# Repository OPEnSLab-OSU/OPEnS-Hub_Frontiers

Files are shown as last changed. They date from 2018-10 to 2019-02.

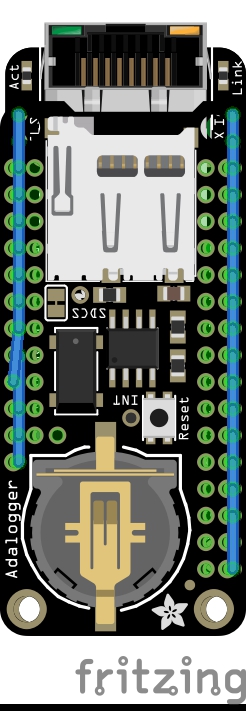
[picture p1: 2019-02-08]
Wiring/HubWiringDiagram_bb.jpg

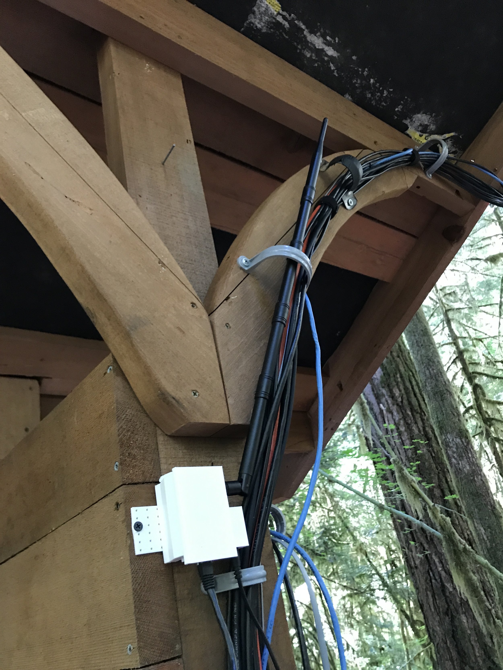
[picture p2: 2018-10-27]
Hub Images/Receiver.jpg

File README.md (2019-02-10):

# OPEnS-Hub_Frontiers


This is the Data, CAD, and Code archive for the OPEnS Hub Project for access by Frontiers

[Project Page](http://www.open-sensing.org/lora-hub)

[Project Loom Repository](https://github.com/OPEnSLab-OSU/InternetOfAg) that this is a instance/subset of 

## Development Boards

This project used the Adafruit line of Development boards called [Feathers](https://www.adafruit.com/feather?gclid=EAIaIQobChMIz5DNofCb4AIVWB6tBh2Vhga1EAAYASAAEgLMxPD_BwE) and [FeatherWings](https://www.adafruit.com/category/814)

Specifically 
* [Adafruit's M0 LoRa RFM95 Feather](https://www.adafruit.com/product/3178) 
* [Adafruit's Ethernet FeatherWing ](https://www.adafruit.com/product/3201) 
* [Adafruit's Adalogger FeatherWing (Real-time Clock and SD Card)](https://www.adafruit.com/product/2922) 

## Bill of Materials
[BOM](https://github.com/OPEnSLab-OSU/OPEnS-Hub_Frontiers/tree/master/BOM)

## Getting Started

Details on setting up Arduino IDE and Code can be found [here](https://github.com/OPEnSLab-OSU/OPEnS-Hub_Frontiers/tree/master/Arduino_and_Loom_Setup)

Details on using the Code  once setup (with examples) can be found [here](https://github.com/OPEnSLab-OSU/InternetOfAg/blob/master/ReadMe_Using_Loom.md)

## Low Power & Real-Time Clock Support

Our dependancy library supports two RTC devices:

- [Adafruit DS3231](https://learn.adafruit.com/adafruit-ds3231-precision-rtc-breakout/)
- [Adafruit PCF8523](https://learn.adafruit.com/adafruit-adalogger-featherwing)

Currently, interrupts (for waking the microprocessor from sleep) are only supported via the DS3231, with the PCF8523 mostly being used in conjunction with an SD card (as Adafruit Adalogger featherwing has PCF8523 and SD card holder) to provide timestamps.

The Loom Library has support for both devices for returning strings of the date, time, or weekday. Additional timer functions are provided for the DS3231.

#### RTC and Low Power Dependencies

- [DS3231 Extended Library](https://github.com/FabioCuomo/FabioCuomo-DS3231)
- [Low Power Library](https://github.com/rocketscream/Low-Power)
- [Enable Interrupt](https://github.com/GreyGnome/EnableInterrupt)

**NOTE:** To use the DS3231 extended library with the Feather M0,
the following line must be added to `RTClibExtended.h`:

```cpp
#define _BV(bit) (1 << (bit))
```

#### Sleep Modes

Project Loom supports two sleep modes for the Feather M0 and one sleep mode for the Feather 32u4.
Here are some details on the various modes:

| Mode | Supported board | Current Draw |
| --- | --- | --- |
| Idle\_2 | Feather M0 | ~5 mA |
| Standby | Feather M0 | ~0.7 mA |

#### Standby Operation

Due to some incompatibilities between Standby mode and falling interrupts, a very particular
scheme must be followed to use Standby mode on the Feather M0.  The following code is an
example of how standby mode can be set up on the M0 with a wakeup interrupt on pin 11:

``` cpp
void setup() {
    pinMode(11, INPUT_PULLUP);
    bool OperationFlag = false;
    delay(10000); //It's important to leave a delay so the board can more easily
                  //be reprogrammed
}

void loop() {
    if (OperationFlag) {

        // Whatever you want the board to do while awake goes here

        OperationFlag = false; //reset the flag
    }

    attachInterrupt(digitalPinToInterrupt(11), wake, LOW);

    LowPower.standby();
}

void wake() {
    OperationFlag = true;
    detachInterrupt(digitalPinToInterrupt(11)); //detach the interrupt in the ISR so that
                                                //multiple ISRs are not called
}
```

## Supporting Files

- [Adafruit References](https://github.com/OPEnSLab-OSU/OPEnS-Hub_Frontiers/tree/master/Adafruit%20Reference)
- [CAD Files](https://github.com/OPEnSLab-OSU/OPEnS-Hub_Frontiers/tree/master/CAD)
- [Field Data](https://github.com/OPEnSLab-OSU/OPEnS-Hub_Frontiers/tree/master/Field%20Data)
- [Images](https://github.com/OPEnSLab-OSU/OPEnS-Hub_Frontiers/tree/master/Images)
- [Wiring](https://github.com/OPEnSLab-OSU/OPEnS-Hub_Frontiers/tree/master/Wiring)
- [PushingBox Guide](https://github.com/OPEnSLab-OSU/OPEnS-Hub_Frontiers/tree/master/PushingBox)

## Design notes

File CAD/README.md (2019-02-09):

# CAD Files

These are the SLT files used to 3D print the enclosure for the Hub. The development boards are simply inserted screwed into the guide holes using the machine screws listed in the BOM.

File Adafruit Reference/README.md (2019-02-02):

# Adafruit References
In this folder contains all the technical specifications of the development boards used in this projects. This includes power consumption, wiring tutorials, pin diagrams and other supplementary information regarding the development boards.  Much of the information is beyond the scope of our project but these files are a comprehensive guide to using these devices.

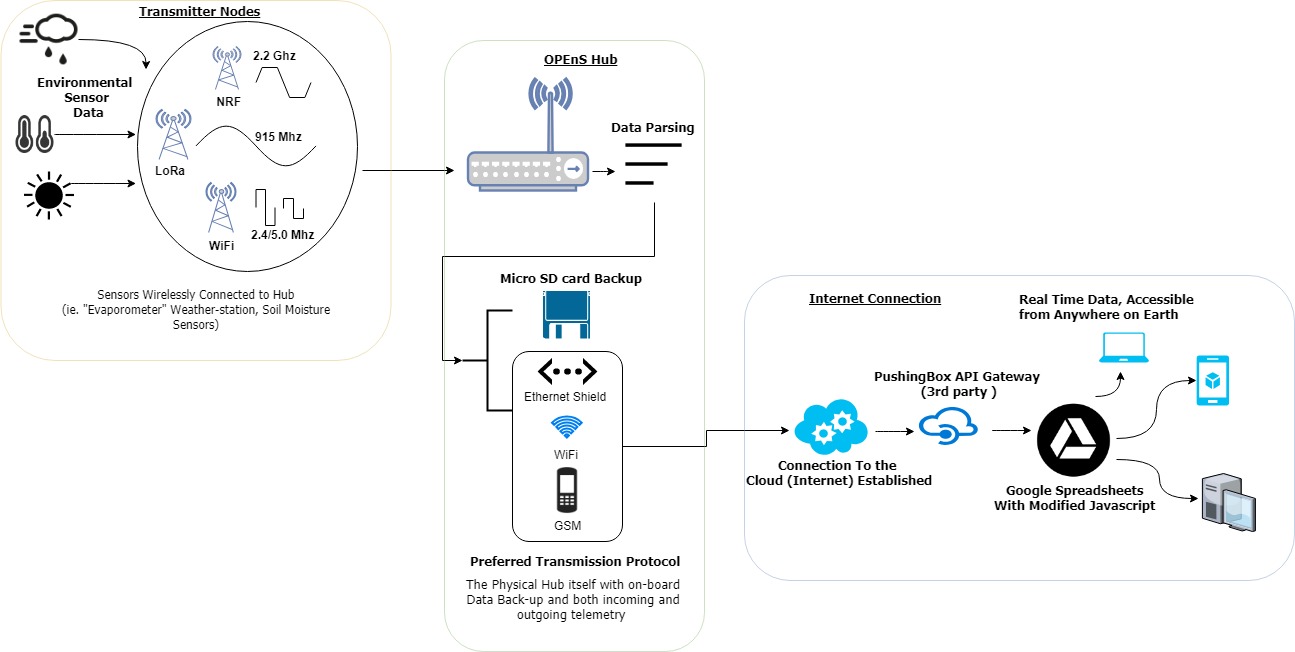
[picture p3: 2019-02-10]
Hub Images/OPEnS Hub (4).jpg

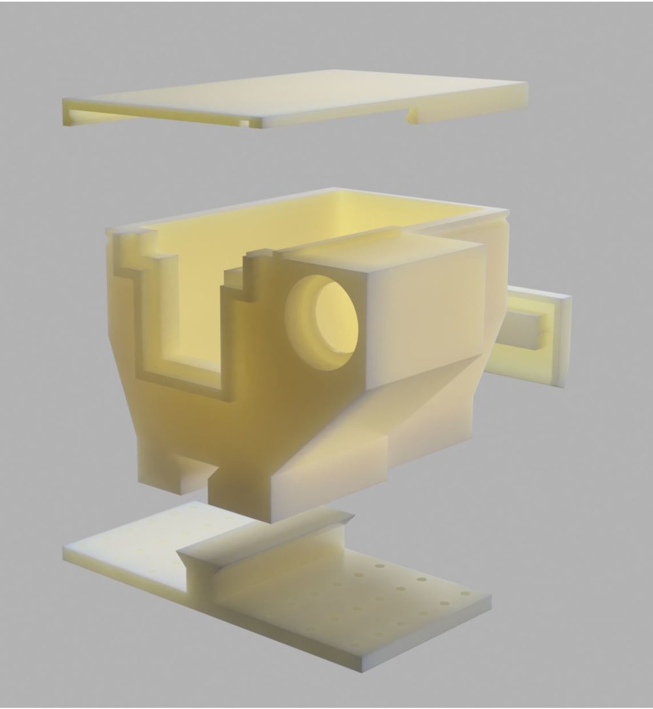
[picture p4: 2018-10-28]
Hub Images/Hub Rendering.jpg

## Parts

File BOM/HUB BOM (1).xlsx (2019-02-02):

Hub Items
Components | Part # | Price Per Unit | # Units | Total | Function | Manufactur/ Districutor
Feather M0 LoRa RFM95 | 3178 | $34.95 | 1 | $34.95 | Development boards with integrated LoRa telemetery | Adafruit (https://www.adafruit.com/product/3178)
900 Mhz LoRa antenna kit |  | $12.75 | 1 | $12.75 | Radio Antenna for extended ranges and required connectors | Adafruit (https://www.adafruit.com/product/3340)
Feather Ethernet shield |  | $19.95 | 1 | $19.95 | For connecting to LAN gateway for internet connections | Adafruit (https://www.adafruit.com/product/3201)
Adalogger (SD Card/Real Time Clock) |  | $7.50 | 1 | $7.50 | Local data logging (Back-up storage) & real-time clock for timestamping transmissions to Hub | Adafruit (https://www.adafruit.com/product/2922)
SD Card |  | $6.70 | 1 | $6.70 | Local Data Logging (Back-up storage) | Amazon (https://www.amazon.com/SanDisk-Mobile-MicroSDHC-SDSDQM-B35A-Adapter/dp/B004ZIENBA?s=pc)
2.1mm Barrel jack |  | $2.95 | 1 | $2.95 | Power jack | Adafruit (https://www.adafruit.com/product/610)
M 2.5 machine screws | SNSS-M2.5-4 | $4.49 | 1 | $4.49 | Mounts development board/SD card to 3D printed enclosure | NBK (https://www.nbk1560.com/en-US/products/specialscrew/nedzicom/miniaturescrew/SNSS/)
3ft Radio extrension |  | $26.84 | 1 | $26.84 | Improves transmission distance to Hub | Lcom (http://www.l-com.com/wireless-antenna-900-mhz-5dbi-rubber-duck-antenna-sma-male-connector)
3D Printed enclosure fabrications cost |  | $12.00 | 1 | $12.00 | In house fabrication cost of 50 cents per gram with a total mass of | OPEnS Lab 3D Printing (http://www.open-sensing.org/opens_scheduling#schedule-lab-time)
 |  |  | Total | $128.13

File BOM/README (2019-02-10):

Links to all parts used in this project can be found in the excel spreadsheet included.
Comparison costs and pricing quotes of specific proprietary providers have been removed out of respect to the respective companies. 
Price quotes are available on request to validate claims made in the report.

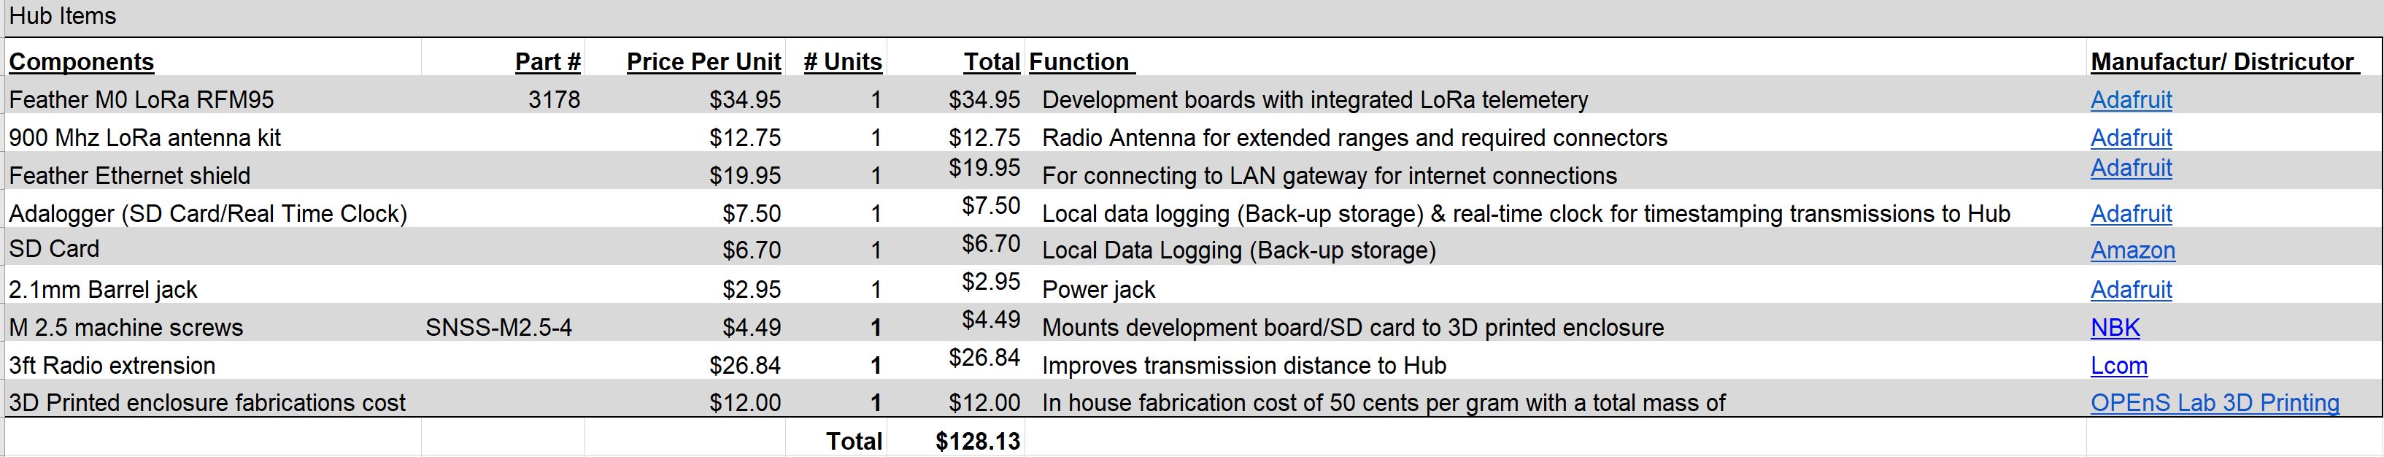
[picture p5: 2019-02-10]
BOM/HubBOMImage.JPG

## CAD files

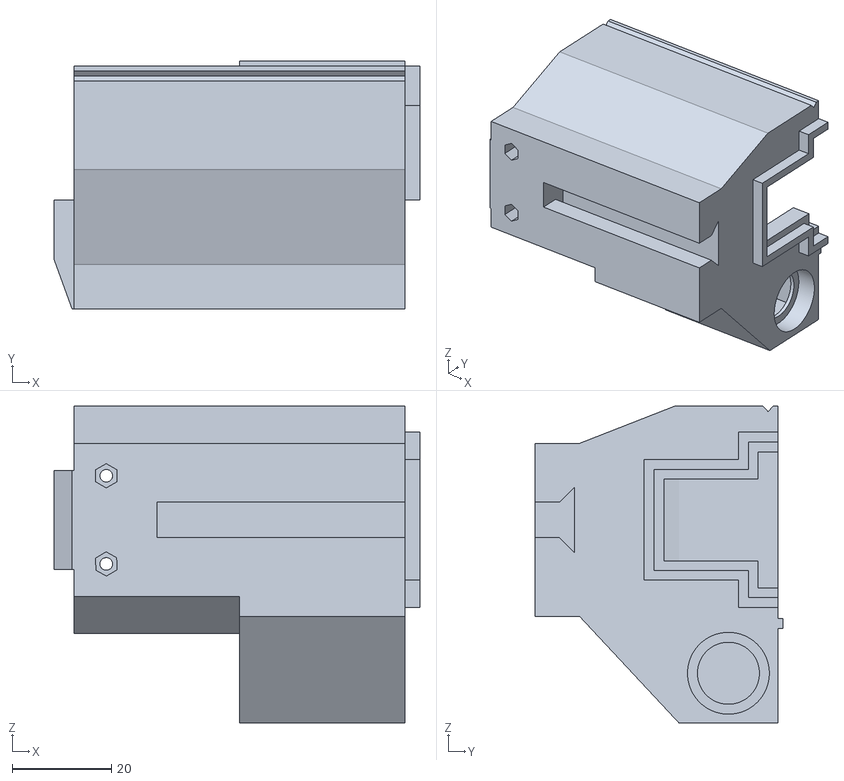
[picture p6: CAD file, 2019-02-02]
CAD/ReceiverCase3 v66.stl
73.8 x 50.0 x 63.9

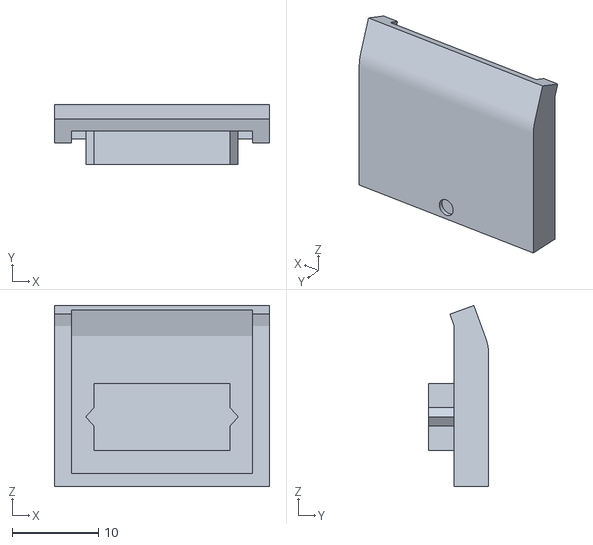
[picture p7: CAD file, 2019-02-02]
CAD/uUSB_Cover v18.stl
25.0 x 7.00 x 21.0

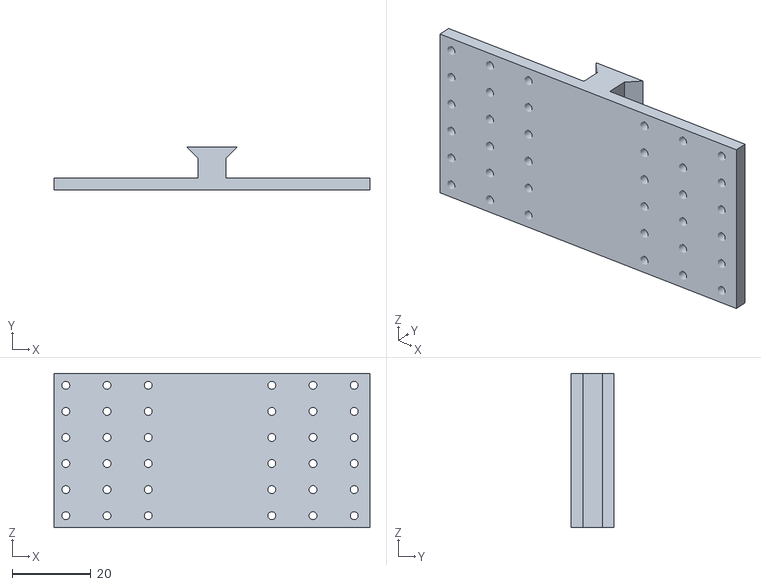
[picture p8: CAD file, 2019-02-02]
CAD/Receiver3_WallAttachment v11.stl
80.0 x 10.8 x 39.0

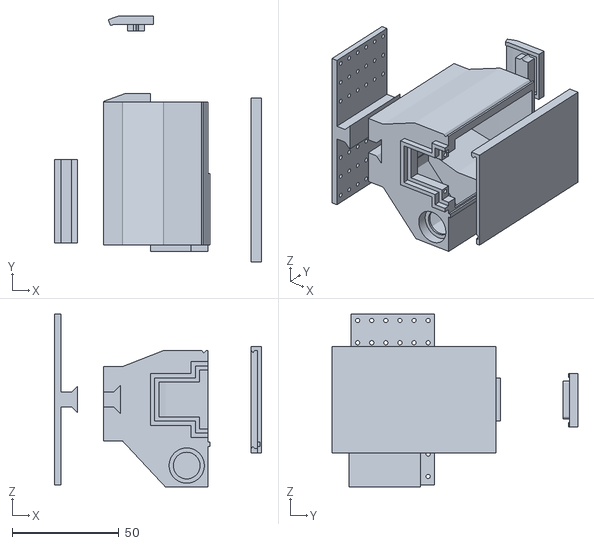
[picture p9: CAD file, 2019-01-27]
CAD/Case3Model.stl
96.9 x 115.1 x 80.9

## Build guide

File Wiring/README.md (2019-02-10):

# Wiring

Included in this folder is the Fritizing file (Software to view and modify this file typce can be found [here](http://fritzing.org/home/) for free!) for the project as well as print outs of the stacked view wiring diagram, the wiring schematic, and PCB exploded view. Additional adafruit Fritizing parts have been uploaded in order to make further modifications. Additional Wiring diagrams can be found in the adafruit reference folder.

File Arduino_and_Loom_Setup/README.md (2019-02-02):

# Arduino and System Setup Guide

Note: much of this set-up is following the Loom protocol developed for the Internet of Ag initative by the OPEnS lab. This language is unimportant for implementing this code base.

## IDE Setup

### **Install the Arduino IDE** 

- Get and install the [Arduino IDE](https://www.arduino.cc/en/Main/Software)
- Follow Adafruit's [instructions](https://learn.adafruit.com/adafruit-feather-m0-basic-proto/overview) on how to:
  - Add the Adafruit boards index
  - Install Adafruit boards
    - Make sure to install the Adafruit SAMD Boards
  - Install drivers if on Windows 7

### **Download the Internet of Ag Library from GitHub**

- Go to the [InternetOfAg](https://github.com/OPEnSLab-OSU/InternetOfAg) folder on GitHub (one directory above this one)

- Click the green 'Clone or Download' button, and 'Download Zip'

- Unzip the downloaded file

### **Install the projects Dependencies**

The all dependecies are provided [here](https://github.com/OPEnSLab-OSU/InternetOfAg/tree/master/Dependencies)

**Mac/Linux**

Either: *(assuming InternetOfAg folder was downloaded to Downloads folder and is unzipped)*

- Find the 'extract_libraries.sh' script from the 'Arduino_and_Loom_Setup' folder from the InternetOfAg download
- Open Terminal
- Drag the script onto the Terminal window
- Press Enter

Or:

- Find the 'Dependencies' folder in the InternetOfAg folder
- Select all of the zip folders
- Right-click and 'Open With' an installed zip extracting application (like Unarchiver)
- Once all of the zip files have been extracted as folders, drag them all to the folder: `Documents/Arduino/libraries ` 

**Windows**

- Find the 'Dependencies' folder in the InternetOfAg folder
- Select all of the zip folders
- Right-click and use 7zip or equivalent to extract the folders
- Once all of the zip files have been extracted as folders, drag them all to the folder: `Documents/Arduino/libraries ` 

### Other Libraries

Install other libraries with the Arduino IDE, as described [here](https://www.arduino.cc/en/guide/libraries)

### **Optional Configuration**

#### **Using an External Editor**

The Arduino IDE editor is a bit limited, so if you want to use a different editor to modify your code, open the Arduino IDE preferences and check the 'Use External Editor' checkbox. This puts a blue tint over the code, and prevents it from being edited in the IDE. Instead, open up your preferred editor to modify your code - anytime you save in that editor, the code in the IDE should update.

**Note –** you will still need to use the IDE to compile and upload your code to the devices 

[Sublime Text](https://www.sublimetext.com) is a great editor you might consider.

## Setup and Usage

**Opening the Code**

Open the `Loom_Library.ino` file from the Loom_Library folder (note that the Arduino IDE requires that any .ino files be in a folder of the same name). This currently opens all of the files of the Loom Library, but there are only two that are of primary concern.

- The .ino file -- this is where you will define the high-level behavior of your device 

- The config.h file -- this is where you will define the hardware your device uses and various behavior options.

*Both files can be renamed, but the .ino file has to match the name of the name of the folder it is within, and the config.h file name should match what is on line 8 of the .ino file (e.g. the '#include "config.h"')*

**Using the Configuration File (config.h)**

- Read the description at the top of the configuration file to understand how it is used
- To start, use the top section of the file to define you best match of your hardware, or some subset (if trying to narrow down issues)

All options have a description to the right

Try to compile your program (check mark icon at the top left of the Arduino IDE)

- If the code does not compile, the reason may be:
  - That you don't have all of the relevant libraries (which shouldn't be the case if you installed all of the libraries following the instructions above)
  - The are some conflicting options set in the configuration file

**Modifying the .ino functionality**

It is recommeded that you base your code off the example provided / use the High-Level API Functions listed at the bottom of the .ino file to for more basic Loom setups. The `loom_interface.h` file describes each of those functions in further detail. 

## Building and Uploading Code Without The IDE

Work is currently be done on investigating and implementing a script that will build the config.h file from the command line, taking the options as arguments. A corresponding Max interface will be made to provide a GUI to these options. The interface will pair with the one to subsequently build and upload code to devices.

The design is planned to be as follows:

- Generate the config file from command line 
  - Arguments to used set options, have default values if none specified
  - Sent to a Python script, inserting the parameters in the relevant locations of the config file
- Be able to call this script from Max
- Use Max to create a graphical interface of toggles / inputs corresponding to the script arguments.
  - Error checking (i.e., of selection conflicts) can be performed in the script or Max, but would doing so in Max would give users immediate feedback on invalid combinations

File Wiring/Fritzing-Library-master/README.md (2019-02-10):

AdaFruit Fritzing Library
==========================

A library of parts for [Fritzing](http://fritzing.org/)

Released under CC Attribution Share-Alike

If you would like to use the entire library, then download AdaFruit.fzbz, Adafruit_Feather.fzbz or Adafruit_Raspberry_Pi.fzbz and open it in Fritzing (File | Open... ) You can git clone or DOWNLOAD with the download button or clicking on https://github.com/adafruit/Fritzing-Library/archive/master.zip

If you wish to make it a permanent resident of your Fritzing parts pallete, use
the drop-down menu in the pallette window and choose "Save Bin".

Individual parts files are located in the "parts" folder. Each of these is in 
the form of an .FZPZ file, which is a standard .ZIP file generated by Fritzing.
They contain all the SVG images and the FPZ part file, and can be opened with a 
standard archive utility like 7-Zip (http://www.7-zip.org/)

NOTE: To use the Arduino Shield parts, and other non-0.1" parts, you must turn off 'align to grid' in the
Breadboard view or they will not align with the Arduino.

As of Feb. 2013 a new /dev directory is included which contains the templates 
used in Inkscape (http://www.inkscape.org) to create the parts in this library.
While you are welcome to use these to create your own Fritzing parts, they are 
here solely for educational purposes, and support will not be provided. 

FOR BEST RESULTS: due to a change in the rendering of SVGs in new versions of 
Fritzing, some older parts may not render correctly. For those old parts, we recommend 
using this library with Fritzing v0.7.5

PLEASE NOTE: 

   * While we enthusiastically encourage you to learn from, modify and 
re-share our Fritzing library, we are not accepting unsolicited Fritzing parts 
for inclusion into this repo. 
   * This library is provided for educational purposes only. We do not guarantee correctness of any part!
   * To request Adafruit parts that are currently not in the repository, open up an issue. We'll try to get to it, but no ETA or promises!
   * You can generate your own lovely files with brd2fpz, check out our tutorial at https://learn.adafruit.com/make-beautiful-fritzing-parts-with-eagle2fritzing-brd2svg

Adafruit Industries is a Friend of Fritzing
============================================

Adafruit is proud to announce we are a "Friend of Fritzing". We've been making
 a ton of Fritzing parts with [johngineer](https://github.com/johngineer) and we've donated to Fritzing to 
encourage more development on this amazing project. The Fritzing team just 
sent us over this spiffy badge!



Fritzing is an open-source initiative to support designers, artists, 
researchers and hobbyists to work creatively with interactive electronics. 
We are creating a software and website in the spirit of Processing and 
Arduino, developing a tool that allows users to document their prototypes, 
share them with others, teach electronics in a classroom, and to create a 
pcb layout for professional manufacturing. 

Fritzing started out as a publicly funded research project from 2007-2009. 
Since 2010 development has relied on the community of users and supporters. 
Adafruit is not a giant company (yet) but we try our best to support 
communities, orgs, schools, companies, events, people and products that share 
our values & goals. From sponsoring events like the Open hardware summit to 
tools like Fritzing, it's part of our mission to help and celebrate open 
source. If you like Fritzing, please considering supporting them as well!

Subparts Art Attribution
============================================
MicroSD Card holder, ESP-12E module, and Bluefruit LE (MDBT40) art is from [PigHixx's](http://www.pighixxx.com/) lovely diagrams!
The pighixx site may not exist anymore but we still want to give attribution!

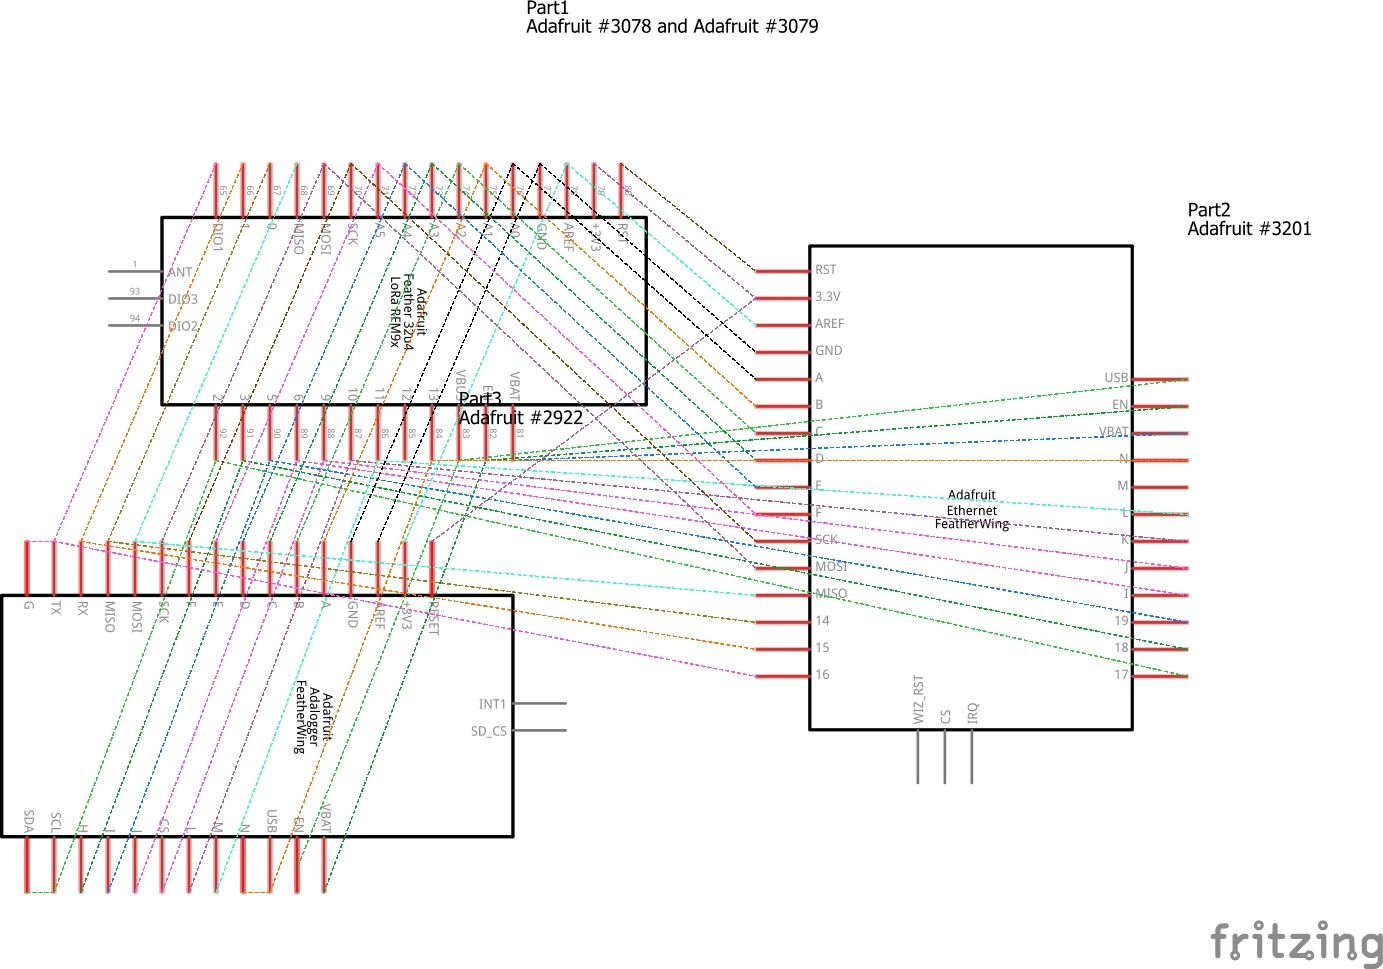
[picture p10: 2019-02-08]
Wiring/HubWiringSchematic_schem.jpg

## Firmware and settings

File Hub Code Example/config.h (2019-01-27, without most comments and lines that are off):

#define FAMILY "EVAP"			// Will usually be "LOOM", you can change this if you are setting up your own network
#define FAMILY_NUM       2		// Specifies the subnet of the family that the device is on. 0 for elevated permissions (can communicate with any subnet), 1-9 for normal
#define CHANNEL          0		// Channel to use. Set to 1-8 for channels A-H, respectively. Alternatively can define to -1 to used advanced option INIT_INST
#define REQUEST_SETTINGS 0		// 1 to request channel settings from Max Channel Manager, 0 to not
#define AUTO_NAME        0		// 1 to enable naming device based on configured settings (if not set manual name in advanced options)
#define CUSTOM_NAME "EvapHub"	// This is only used if Auto_name is set to be 0
#define INIT_INST CHANNEL
#define LOOM_DEBUG    0		// Set to 1 if you want Serial statements from various functions to print
#define dynamic_serial_output 0 // 0 is standard operation
#define hub_node_type 0		// 0: Hub, 1: Node
#define is_repeater   0		// Sorry, this doesn't do anything yet
#define is_wifi       0		// 1 to enable WiFi
#define is_lora       1		// 1 to enable LoRa (cannot be used with nRF) (Further customization in advanced options)
#define is_nrf        0		// 1 to enable nRF (cannot be used with LoRa) (Further customization in advanced options)
#define is_ethernet   1		// 1 to enable Ethernet (a number of options below might auto enable this anyway though)
#define is_fona       0		// 1 to enable cellular via Fona (808)
#define is_bluetooth  0		// Sorry, Bluetooth is not implemented yet
#define is_pushingbox 0		// 1 to enable PushingBox
#define is_adafruitio 0		// 1 to enable Adafruit IO (currently requires WiFi)
#define is_sd         0		// 1 to enable SD card
#define is_rtc        0		// Enable RTC functionality
#define num_servos    0 	// Number of servos being used (up to 8 per shield, testing has generally only been through 1 shield)
#define num_steppers  0		// Number of stepper motors being used
#define is_relay      0		// 1 if relays are being used (enables two, on pins 5 and 6)
#define num_analog    0		// Number of analog inputs being used (0=None ; 1=A0 ; 2=A0,A1 ; 3=A0,A1,A2)
#define is_decagon    0		// 1 if GS3 Decagon is being used
#define is_tsl2591         0	// Lux Sensor
#define is_tsl2561         0	// Lux Sensor
#if is_tsl2561 == 1
	#define tsl2561_res 3 // 1 for fastest, low-res, 2 for middle, 3 for slow, high-res
	#define is_tsl2561_low   1
	#define is_tsl2561_float 1
	#define is_tsl2561_high  1
#endif
#define is_fxos8700        0	// Accelerometer / Magnetometer
#define is_fxas21002       0	// Gyroscope
#define is_zxgesturesensor 0	// ZX_Distance Sensor
#define is_sht31d          0	// Temperature / Humidity
#define is_mb1232          0	// Sonar
#define is_mpu6050         0	// Accelerometer / Gyroscope
#define is_lis3dh          0	// Accelerometer
#define is_ms5803          0	// Atmospheric Pressure / Temperature Sensor
#define is_hx711           0    // Load Cell
#if is_hx711 == 1
	#define hx711_calibration 961.275
#endif
#define is_button 		0	// 1 to enable button
#define button_pin 		10	// Using on-board button, specify attached pin, transmitting
#define is_ishield      0	// 1 to specify using Ishield (should enable only wifi as communication platform)
#define is_multiplexer  0	// 1 if tca9548a Multiplexer is being used. (Further customization in advanced options)
#define is_sapflow      0
#define is_evaporimeter 0
#if is_wifi == 1
	#define DEFAULT_MODE      WPA_CLIENT_MODE	// AP_MODE, WPA_CLIENT_MODE or WEP_CLIENT_MODE
	#define DEFAULT_NETWORK   "OPEnS"			// Network SSID / name
	#define DEFAULT_PASSWORD  "arduino101"		// Network password
#endif
#define enable_hub_scripts 0
#define advanced_interdev_comm   0	// Used for Max-like functionality
#define build_actuator_cmd_funcs 0  // 1 to include file to make commands for Loom actuators
#define wake_delay 0	// 1 to enable wait 5 seconds upon awaking from sleep to start serial
#if CHANNEL == -1
	#define INIT_INST    3	// Initial device instance number (normally 1-8 when using channels)
	#define INIT_PORT 9443	// Initial device UDP port (normally 1-8 when using channels)
#endif
#if is_wifi == 1
	#define advanced_interdev_comm 1  // Enable for full Max support
#endif
#if is_rtc == 1
	#define RTC_pin 6
	#define is_rtc3231 1 	// RTC DS 3231 Featherwing
	#define is_rtc8523 0	// RTC Adalogger Featherwing with PCF8523 RTC (the one with SD card)
#endif
#if is_multiplexer == 1
	#define UPDATE_PERIOD 5000		// Milliseconds between multiplexer sensor list being updated
	#define is_tsl2591         1	// Lux Sensor
	#define is_tsl2561         1	// Lux Sensor
	#define is_fxos8700        1	// Accelerometer / Magnetometer
	#define is_fxas21002       1	// Gyroscope
	#define is_zxgesturesensor 1	// ZX_Distance Sensor
	#define is_sht31d          1	// Temperature / Humidity
	#define is_mb1232          1	// Sonar
	#define is_mpu6050         1	// Accelerometer / Gyroscope
	#define is_lis3dh          1    // Accelerometer
	#define is_ms5803          1	// Pressure Sensor
#endif
#if is_ishield == 1
	#define is_button   1			// 1 to enable button
	#define button_pin  10
	#define is_mpu6050  0			// Enables MPU6050 on Ishield
	#define is_neopixel 1			// Toggle based on whether Neopixels are being used
	#if is_neopixel == 1			// Which Ishield ports to enable Neopixels for
		#define NEO_0   0			// Port 0 (A0, closest to end of Ishield)
		#define NEO_1   0			// Port 1 (A1, middle port)
		#define NEO_2   1			// Port 2 (A2, port closest to MPU6050)
	#endif
#endif
#if is_sapflow == 1
	#define is_lora           1      // enable LoRa
	#define is_rtc            1
	#define is_sd             1
	#if hub_node_type == 0       // if is hub
		#define is_ethernet   1
		#define is_pushingbox 1
	#elif hub_node_type == 1     // if is node
		#define num_analog    2      // two temperature sensors
		#define probe_type    0      // 0:TDM, 1: HRM
    #define is_sht31d     1      // Temperature / Humidity
    #define is_decagon    1      // Soil moisture
		#define heatpulse     2500   // For HRM probe heat pulse (e.g 2500:2.5 sec)
		#define senddelay     60000  // send data every 1 min
    #define heatduration  30000  // Turn on heater for 30 sec
	#endif
#endif
#if is_evaporimeter == 1
	#define hub_node_type 1
	#define is_lora 1
	#define is_tsl2561 1
		#define is_tsl2561_low   1
		#define is_tsl2561_float 1
		#define is_tsl2561_high  0
	#define is_hx711 1
	#if is_hx711 == 1
		#define hx711_calibration 961.275 // grams
	#endif
	#define is_sht31d 1
	#define is_rtc 1
	#if is_rtc == 1
		#define RTC_pin    6
		#define is_rtc3231 1
		#define is_rtc8523 0
	#endif
	#define is_button  0
#endif
#if is_lora == 1
	#if hub_node_type == 0 // is hub
		#define LORA_HUB_ADDRESS  CHANNEL
		#define LORA_NODE_ADDRESS 9
	#else // is node
		#define LORA_HUB_ADDRESS  1			// 10 CLIENT_ADDRESSes belong to each SERVER_ADDRESS,
		#define LORA_NODE_ADDRESS CHANNEL
	#endif
	#define RF95_FREQ      915.0		// Hardware specific, Tx must match Rx
#endif
#if is_nrf == 1
	#define NRF_HUB_ADDRESS 1			// Use 0-9 for SERVER_ADDRESSes
	#if hub_node_type == 1
		#define NRF_NODE_ADDRESS 0
	#endif
#endif
#if is_ethernet == 1
	#include <Ethernet2.h>				// (this is needed for IPAddress object below, do not remove)
	 byte mac[] = {0x98, 0x76, 0xB6, 0x10, 0x61, 0xD6};
	IPAddress ip(128,193,56,138); 						  // device's IP address  				try to make this a string, so #include can be move to ethernet file
#endif
#if is_fona == 1
	#define LOOM_DEBUG 1	// This is just temporary for now, as all Fona tests are done interactively through serial monitor
	#define fona_test  1    // This enables the Fona interactive testing Loop, note that this will override normal
	#define fona_type 2G 	// Can be '2G' (808) or '3G' (5320A), currently only 2G is supported
#endif
#if (hub_node_type == 0) && ((is_wifi == 1) || (is_ethernet == 1) || (is_fona == 1))
	#define is_pushingbox 1 // only if Ethernet, WiFi, or cellular
	#define device_poll_refresh 0  // Seconds between re-searching for devices on the network
#endif
#if (is_ethernet != 1) && (is_wifi != 1) && (is_fona != 1)
	#define is_pushingbox 0
#endif
#if is_pushingbox == 1
	#define spreadsheet_id "1Hv2oME5sjumUXv36GtFV1Q7I83xnXu-f-ZrxUNsXS_U"  // This is Luke's Arduino Test spreadsheet
	char device_id[]   = "v7ECCEF7A460E57A";
	#define useHubTabID 0
	#if useHubTabID == 1
		#define tab_id_complete "Sheet1"    // Defines tab if hub is defining tab instead of bundle source
	#else
		#define tab_id_prefix   "Lab_"		// Used as a prefix if bundle source is being used to define tab
	#endif
	#define verify_family_match 1
	#define pushMillisFilter 0 // 1 to enable a millis delay to uploading to PushingBox
	#define pushMillisDelay 5  // delay in seconds
#endif
#if is_adafruitio == 1
	#define AIO_USERNAME    "Goertzel"
	#define AIO_KEY         ""
#endif
#if is_sd
	#define sd_save_time_format 3
#endif
#if is_lora == 0 						// Cannot not use with LoRa
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

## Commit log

2019-01-26 Development Board Documentation
    Contained within these documents are the all manufacturers information pertaining to the specific power requirements, hardware capabilities and ...
2019-01-27 Field data folder
    [HJ Andrews Forest Datalog (7_27_17-9_21_17).xlsx, HJA_EvaporometersPhase2 (8_28_18-9_15_18).xlsx, LB Farms Multi_Sensor_type_Data(4_17_18-6_1_18).xlsx]
2019-01-27 Add files via upload
    This is the 3D CAD file for the enclosure used in all field deployments for the Hub.
    [Case3Model.stl]
2019-02-02 Additional Print Files
    Additional Print Files
    [Receiver3_WallAttachment v11.stl, ReceiverCase3 v66.stl, uUSB_Cover v18.stl]
2019-02-02 Create HUB BOM.xlsx
    [HUB BOM.xlsx]
2019-02-02 updated BOM
    [HUB BOM (1).xlsx, HUB BOM.xlsx]
2019-02-08 Create HubWiringDiagram.fzz
    The software needed to view/modifey this wiring diagram can be found here (http://fritzing.org/home/) for free!
    [HubWiringDiagram.fzz]
2019-02-08 More Image Files
    This now includes the Wiring Diagram showing how the PCB's can be stacked vertically on top of eachother, as well as the detailed wiring schematic and a PCB expanded view.
2019-02-10 Update README.md
    Low power info added
2019-02-10 Low Power
